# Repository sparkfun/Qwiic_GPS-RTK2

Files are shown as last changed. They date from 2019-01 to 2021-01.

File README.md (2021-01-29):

SparkFun Ublox GPS-RTK-SMA (Qwiic) - ZED-F9P
===========================================================

SparkFun GPS-RTK-SMA - ZED-F9P (https://www.sparkfun.com/products/16481)

[*SparkFun GPS-RTK-SMA - ZED-F9P (GPS-16481)*](https://www.sparkfun.com/products/16481)

The ZED-F9P module is the top-of-the-line module for high accuracy GNSS and GPS location solutions including RTK. The ZED-F9P is unique in that it can receive both L1 and L2 GPS bands as well as up to four constellations (GPS, GLONASS, BeiDou, Galileo) at the same time. This module is capable of 10mm positional accuracy and has survey-in mode allowing the module to become a base station and produce RTCM 3.x correction data. 

**Words, words, words. What does it look like?!** I'm glad you asked!

SparkFun GPS-RTK2 - ZED-F9P (https://www.sparkfun.com/products/16481)

With *33* satellites used in the location solution.

Repository Contents
-------------------

* **/Documents** - Ublox datasheets and various whitepapers around RTK
* **/Hardware** - Eagle files

Documentation
--------------

* **[Installing an Arduino Library Guide](https://learn.sparkfun.com/tutorials/installing-an-arduino-library)** - Basic information on how to install an Arduino library.
* **[Arduino Library](https://github.com/sparkfun/SparkFun_u-blox_GNSS_Arduino_Library)** - Arduino Library for Ublox modules.
* **[Hookup Guide](https://learn.sparkfun.com/tutorials/gps-rtk2-hookup-guide)** - Hookup guide for the SparkFun Ublox GPS-RTK-SMA.

License Information
-------------------

This product is _**open source**_! 

Various bits of the code have different licenses applied. Anything SparkFun wrote is beerware; if you see me (or any other SparkFun employee) at the local, and you've found our code helpful, please buy us a round!

Please use, reuse, and modify these files as you see fit. Please maintain attribution to SparkFun Electronics and release anything derivative under the same license.

Distributed as-is; no warranty is given.

- Your friends at SparkFun.

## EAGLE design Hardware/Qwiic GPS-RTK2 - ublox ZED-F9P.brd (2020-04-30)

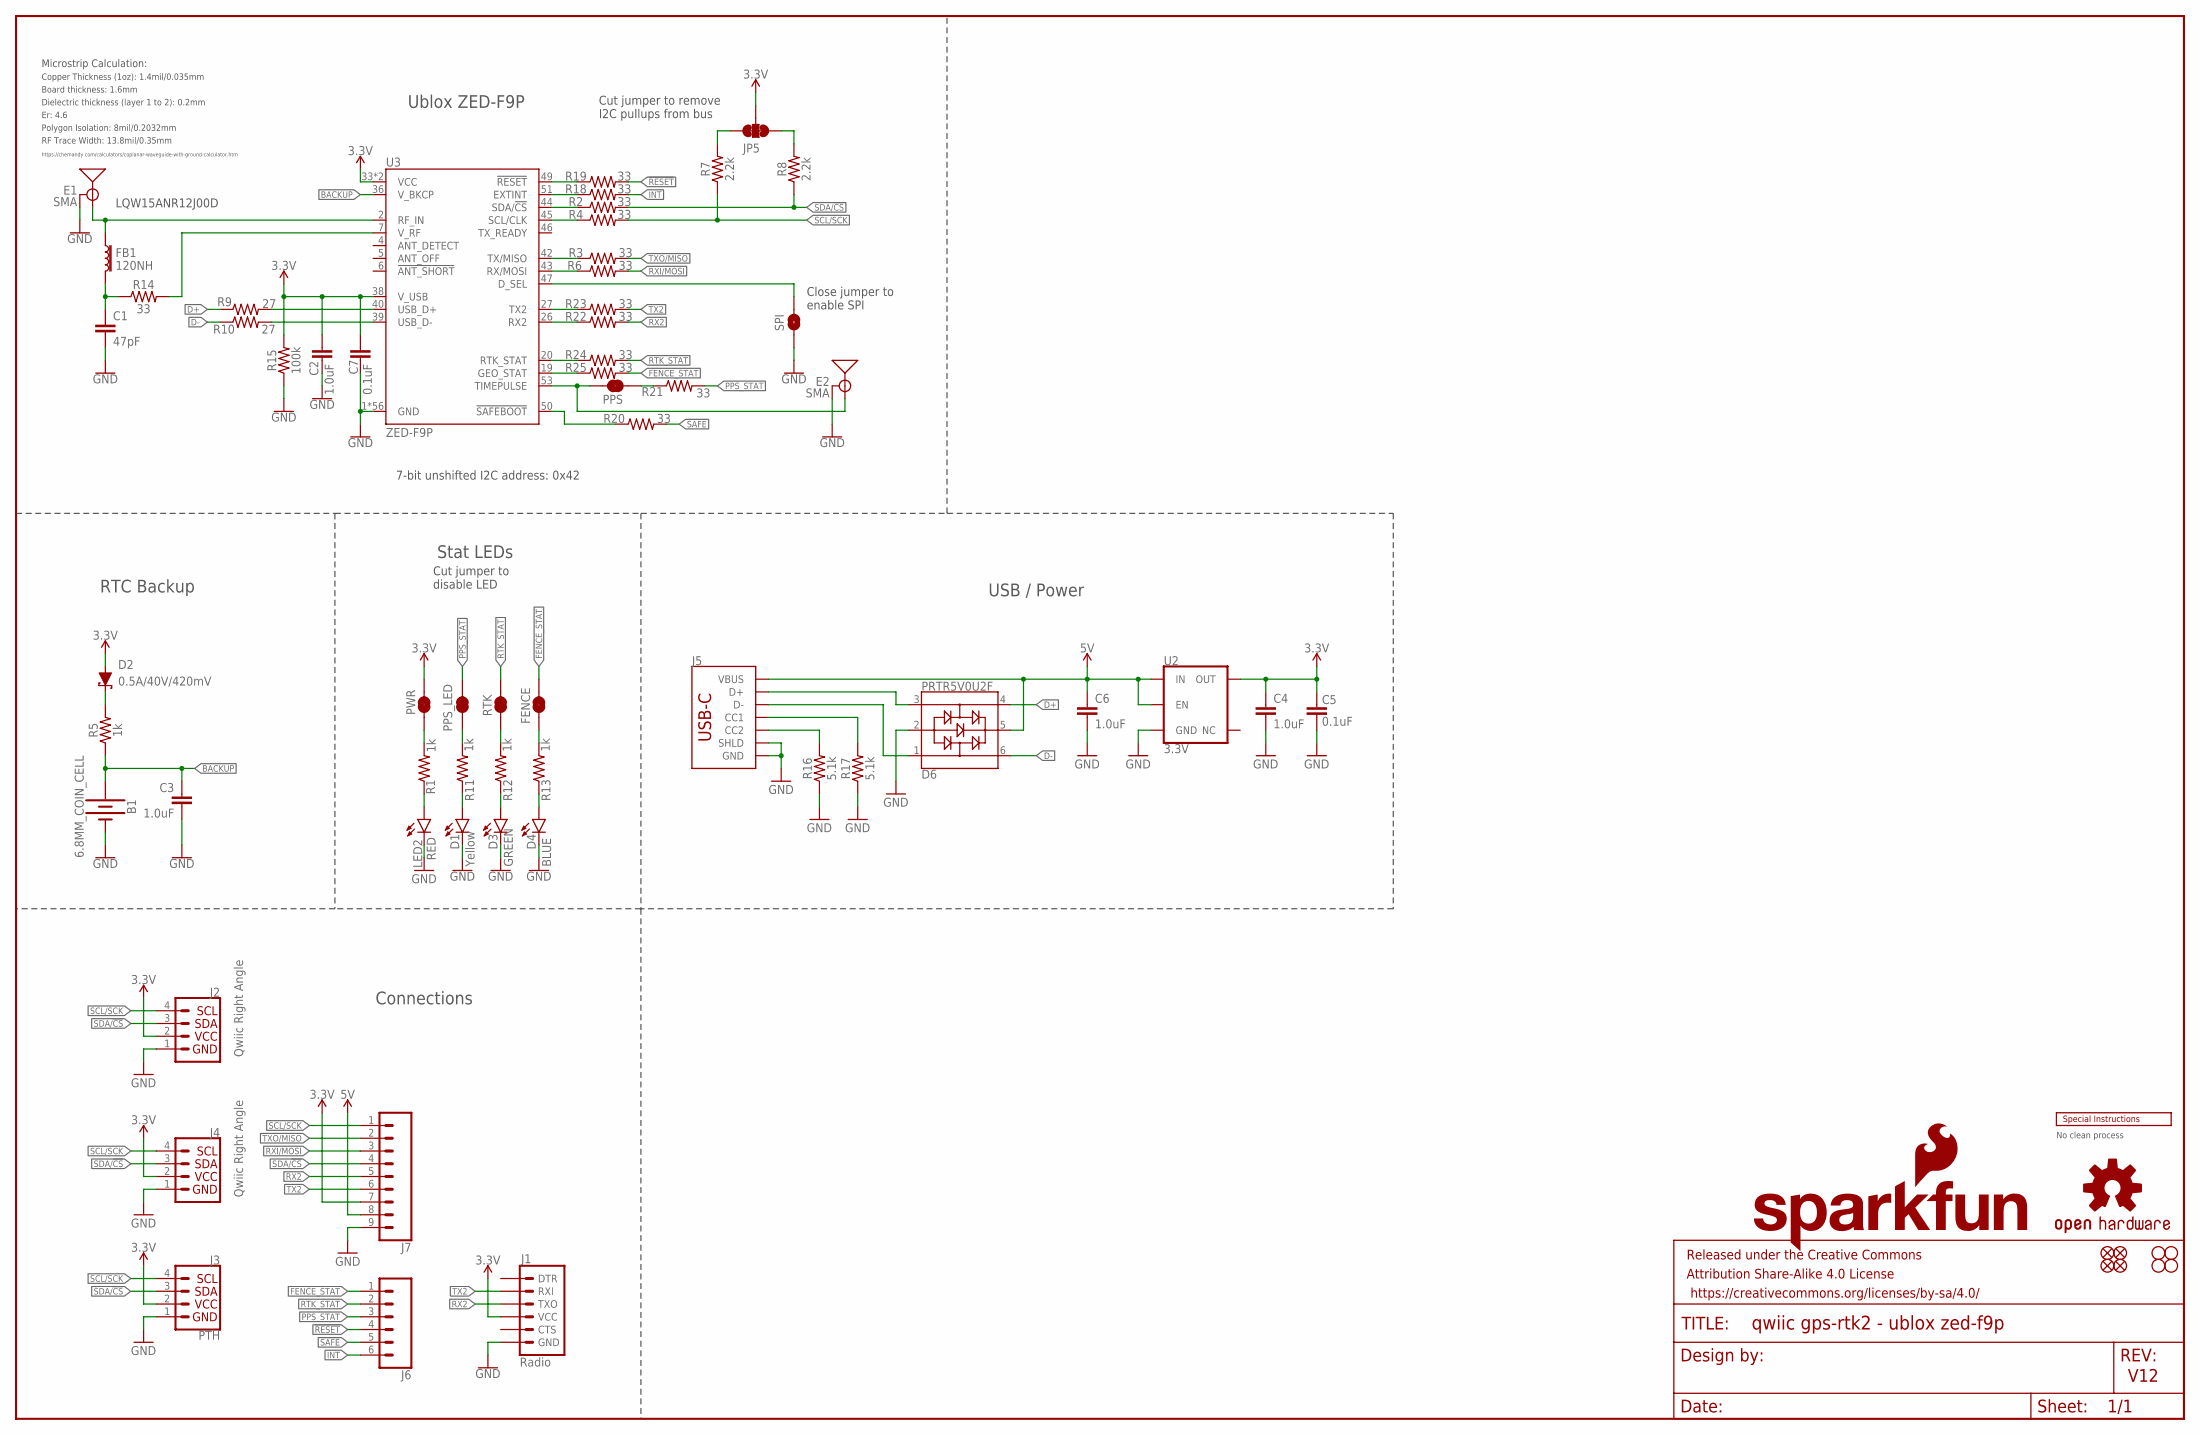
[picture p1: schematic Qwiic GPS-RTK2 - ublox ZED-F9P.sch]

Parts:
B1: 6.8MM_COIN_CELL; ML414H_IV01E
C1: 47pF; 0402
C2, C3, C4, C6: 1.0uF; 0603
C5, C7: 0.1uF; 0603
D1: Yellow; LED-0603
D2: 0.5A/40V/420mV; SOD-323
D3: GREEN; LED-0603
D4: BLUE; LED-0603
D6: PRTR5V0U2F; SOT886
E1, E2: SMA; SMA-EDGE
FB1: 120NH; 0402_MURATA
FENCE: JUMPER-SMT_2_NC_TRACE_SILK; SMT-JUMPER_2_NC_TRACE_SILK
FRAME2: FRAME-LEDGER; CREATIVE_COMMONS
J1: Radio; 1X06_NO_SILK
J2, J4: Qwiic Right Angle; JST04_1MM_RA
J3: PTH; 1X04_NO_SILK
J5: USB_C_2-LAYER_PADS; USB-C-16P-2LAYER-PADS
J6: CONN_06NO_SILK_FEMALE_PTH; 1X06_NO_SILK
J7: CONN_09NO_SILK; 1X09_NO_SILK
JP5: JUMPER-SMT_3_2-NC_TRACE_SILK; SMT-JUMPER_3_2-NC_TRACE_SILK
JP21, JP61, JP71, JP81: FIDUCIALUFIDUCIAL; MICRO-FIDUCIAL
JP31, JP41, JP91, JP101: STAND-OFF
LED2: RED; LED-0603
LOGO1: OSHW-LOGOMINI; OSHW-LOGO-MINI
LOGO2: SFE_LOGO_NAME_FLAME.1_INCH; SFE_LOGO_NAME_FLAME_.1
PPS: JUMPER-SMT_2_NC_TRACE_SILK; SMT-JUMPER_2_NC_TRACE_SILK
PPS_LED: JUMPER-SMT_2_NC_TRACE_SILK; SMT-JUMPER_2_NC_TRACE_SILK
PWR: JUMPER-SMT_2_NC_TRACE_SILK; SMT-JUMPER_2_NC_TRACE_SILK
R1, R5, R11, R12, R13: 1k; 0603
R2, R3, R4, R6, R14, R18, R19, R20, R21, R22, R23, R24, R25: 33; 0603
R7, R8: 2.2k; 0603
R9, R10: 27; 0603
R15: 100k; 0603
R16, R17: 5.1k; 0603
RTK: JUMPER-SMT_2_NC_TRACE_SILK; SMT-JUMPER_2_NC_TRACE_SILK
SPI: JUMPER-SMT_2_NO_SILK; SMT-JUMPER_2_NO_SILK
U2: 3.3V; SOT23-5
U3: ZED-F9P
U$2: SPECIAL_INSTRUCTIONS-ORDERING; ORDERING_INSTRUCTIONS

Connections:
3.3V: C2.1, C4.1, C5.2, C7.2, D2.A, J1.4 (VCC), J2.2, J3.2 (VCC), J4.2, J7.7, JP5.2, PWR.2, R15.2, U2.5 (OUT), U3.33 (VCC), U3.34 (VCC), U3.38 (V_USB)
5V: C6.1, D6.5, J5.VBUS1 (VBUS), J5.VBUS2 (VBUS), J7.8, U2.1 (IN), U2.3 (EN)
!RESET: J6.4, R19.2
!SAFE: J6.5, R20.2
ANT_VCC: C1.1, FB1.P2 (2), R14.1
BACKUP: B1.+, C3.1, R5.1, U3.36 (V_BKCP)
CC1: J5.A5 (CC1), R17.2
CC2: J5.B5 (CC2), R16.2
D+: D6.4, R9.1
D-: D6.6, R10.1
D_SEL: SPI.2, U3.47 (D_SEL)
FENCE_STAT: FENCE.2, J6.1, R25.2
GND: B1.-, C1.2, C2.2, C3.2, C4.2, C5.1, C6.2, C7.1, D1.C, D3.C, D4.C, D6.2, E1.GND@0 (GND), E1.GND@1 (GND), E1.GND@2 (GND), E1.GND@3 (GND), E2.GND@0 (GND), E2.GND@1 (GND), E2.GND@2 (GND), E2.GND@3 (GND), J1.6 (GND), J2.1, J3.1 (GND), J4.1, J5.GND, J5.GND2 (GND), J5.SHLD1 (SHLD), J5.SHLD2 (SHLD), J5.SHLD3 (SHLD), J5.SHLD4 (SHLD), J7.9, LED2.C, R15.1, R16.1, R17.1, SPI.1, U2.2 (GND), U3.1 (GND), U3.3 (GND), U3.12 (GND), U3.14 (GND), U3.32 (GND), U3.37 (GND), U3.41 (GND), U3.48 (GND), U3.55 (GND), U3.56 (GND), U3.57 (GND), U3.58 (GND), U3.59 (GND), U3.60 (GND), U3.61 (GND), U3.62 (GND), U3.63 (GND), U3.64 (GND), U3.65 (GND), U3.66 (GND), U3.67 (GND), U3.68 (GND), U3.69 (GND), U3.70 (GND), U3.71 (GND), U3.72 (GND), U3.73 (GND), U3.74 (GND), U3.75 (GND), U3.76 (GND), U3.77 (GND), U3.78 (GND), U3.79 (GND), U3.80 (GND), U3.81 (GND), U3.82 (GND), U3.83 (GND), U3.84 (GND), U3.85 (GND), U3.86 (GND), U3.87 (GND), U3.88 (GND), U3.89 (GND), U3.90 (GND), U3.91 (GND), U3.92 (GND), U3.93 (GND), U3.94 (GND), U3.95 (GND), U3.96 (GND), U3.97 (GND), U3.98 (GND), U3.99 (GND), U3.100 (GND), U3.101 (GND), U3.102 (GND)
GPS_ANT1: E1.SIG (SIGNAL), FB1.P1 (1), U3.2 (RF_IN)
INT: J6.6, R18.2
unnamed: D3.A, R12.1
unnamed: D1.A, R11.1
unnamed: R12.2, RTK.1
unnamed: PPS_LED.1, R11.2
unnamed: JP5.1, R8.2
unnamed: D2.C, R5.2
unnamed: D4.A, R13.1
unnamed: JP5.3, R7.2
unnamed: FENCE.1, R13.2
unnamed: LED2.A, R1.1
unnamed: R9.2, U3.40 (USB_D+)
unnamed: R10.2, U3.39 (USB_D-)
unnamed: R14.2, U3.7 (V_RF)
unnamed: R22.1, U3.26 (RX2)
unnamed: R18.1, U3.51 (EXTINT)
unnamed: R19.1, U3.49 (!RESET!)
unnamed: PWR.1, R1.2
unnamed: R20.1, U3.50 (!SAFEBOOT!)
unnamed: R24.1, U3.20 (RTK_STAT)
unnamed: R25.1, U3.19 (GEO_STAT)
unnamed: PPS.1, R21.1
PPS: E2.SIG (SIGNAL), PPS.2, U3.53 (TIMEPULSE)
PPS_STAT: J6.3, PPS_LED.2, R21.2
RTK_STAT: J6.2, R24.2, RTK.2
RX2: J1.3 (TXO), J7.5, R22.2
RXI/MOSI: J7.3, R6.2
RXLV: R6.1, U3.43 (RX/MOSI)
SCL/SCK: J2.4, J3.4 (SCL), J4.4, J7.1, R4.2, R7.1
SCL_LV: R4.1, U3.45 (SCL/CLK)
SDA/!CS: J2.3, J3.3 (SDA), J4.3, J7.4, R2.2, R8.1
SDA_LV: R2.1, U3.44 (SDA/!CS!)
TX2: J1.2 (RXI), J7.6, R23.2
TX2_P: R23.1, U3.27 (TX2)
TXLV: R3.1, U3.42 (TX/MISO)
TXO/MISO: J7.2, R3.2
UNP_D+: D6.3, J5.A6 (D+), J5.B6 (D+)
UNP_D-: D6.1, J5.A7 (D-), J5.B7 (D-)

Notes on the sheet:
V12
7-bit unshifted I2C address: 0x42
Ublox ZED-F9P
RTC Backup
Stat LEDs
Cut jumper to remove I2C pullups from bus
Cut jumper to disable LED
Close jumper to enable SPI
LQW15ANR12J00D
Board thickness: 1.6mm
Er: 4.6
Copper Thickness (1oz): 1.4mil/0.035mm
RF Trace Width: 13.8mil/0.35mm
Polygon Isolation: 8mil/0.2032mm
No clean process
Dielectric thickness (layer 1 to 2): 0.2mm
https://chemandy.com/calculators/coplanar-waveguide-with-ground-calculator.htm
Microstrip Calculation:
Connections
USB / Power

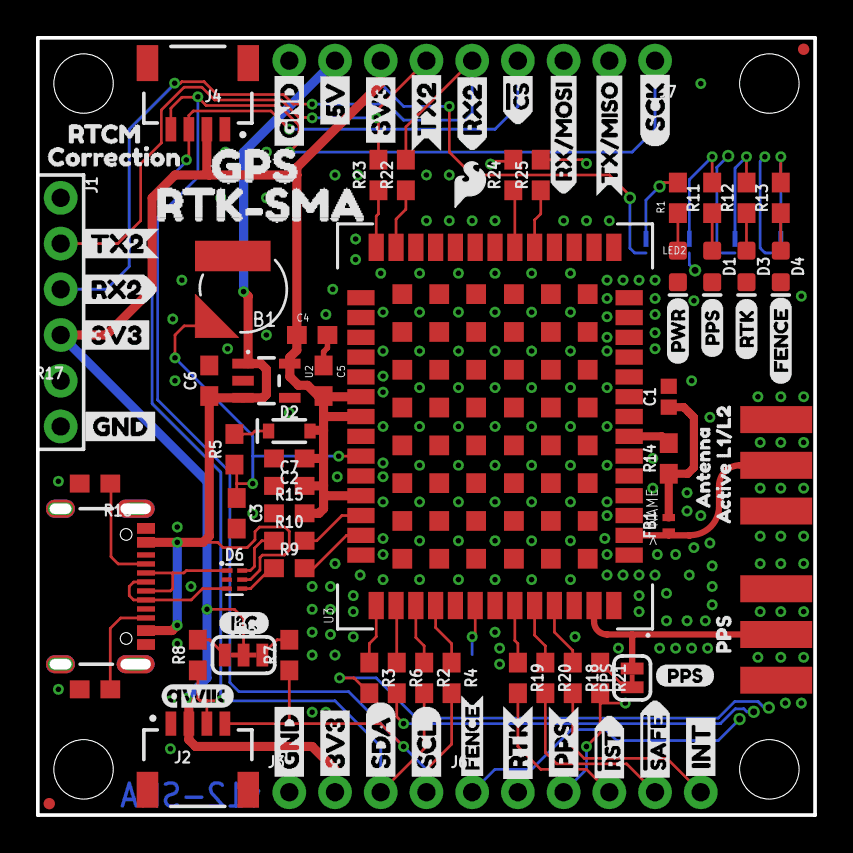
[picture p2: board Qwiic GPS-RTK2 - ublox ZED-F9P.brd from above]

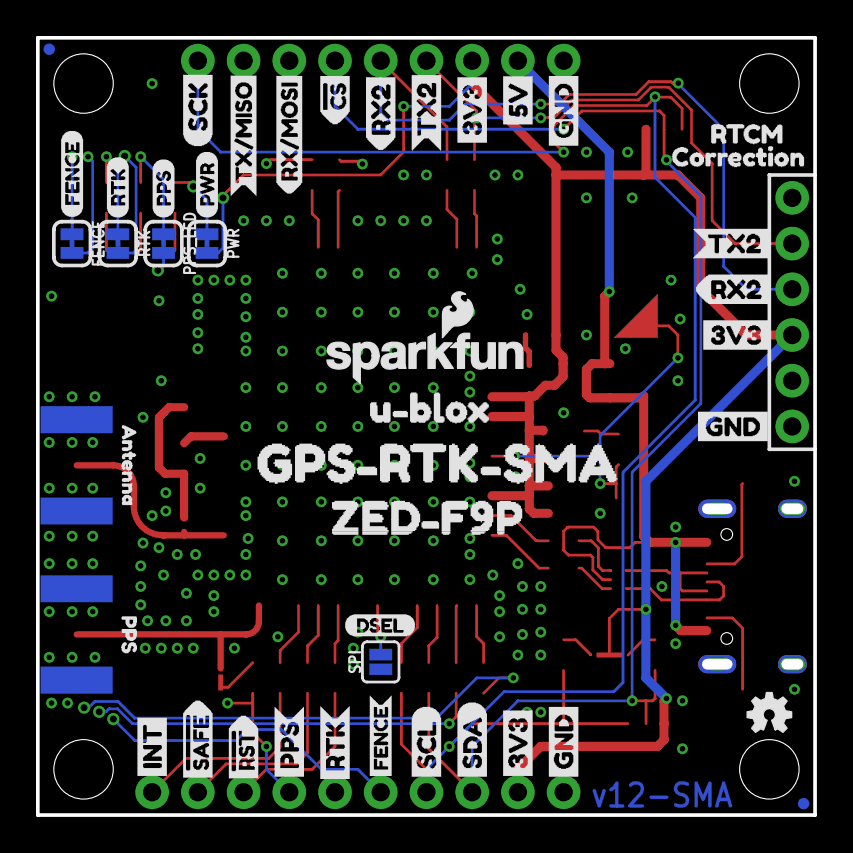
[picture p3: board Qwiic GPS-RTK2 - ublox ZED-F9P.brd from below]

Board: 4 copper layers, 43.2 x 43.2 mm, 143 parts (44 on the bottom side), 52 nets.

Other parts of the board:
U$1, U$4: SDA-[)
U$3, U$5: SCL-[)
U$6, U$7, U$60, U$61, U$66, U$67: 3V3-04
U$8, U$9, U$62, U$63: GND-04
U$10: I_SUPER2_C-()-03
U$11, U$54: FENCE2
U$12, U$18: PWR-()-03
U$13, U$28, U$29, U$32: RTK1
U$14, U$17: FENCE0
U$15, U$16: INT8
U$19, U$20: 5V
U$21, U$56, U$58: RX20
U$22: U#BLOX3
U$23, U$24: CS#-<]
U$25, U$52, U$72: PPS0
U$26, U$31: RX#MOSI3
U$27: DSEL0
U$30: QWIIC_4MM
U$33: SFE_LOGO_FLAME_.1
U$34, U$37: TX#MISO1
U$35, U$36: #RST3
U$38, U$41: SCK-(]-04
U$39, U$40: #SAFE1
U$42: RX22
U$43, U$44: PPS5
U$45, U$68: GND3
U$47, U$74: PPS1
U$48, U$70: RTCM5
U$49: ZED#F9P6
U$50, U$55, U$57: TX21
U$51: TX23
U$53, U$69: CORRECTION0
U$59: GPS0
U$65: ACTIVE_L1#L21
U$71, U$75: ANTENNA2
U$73: RTK#SMA4
U$76: GPS#RTK#SMA5

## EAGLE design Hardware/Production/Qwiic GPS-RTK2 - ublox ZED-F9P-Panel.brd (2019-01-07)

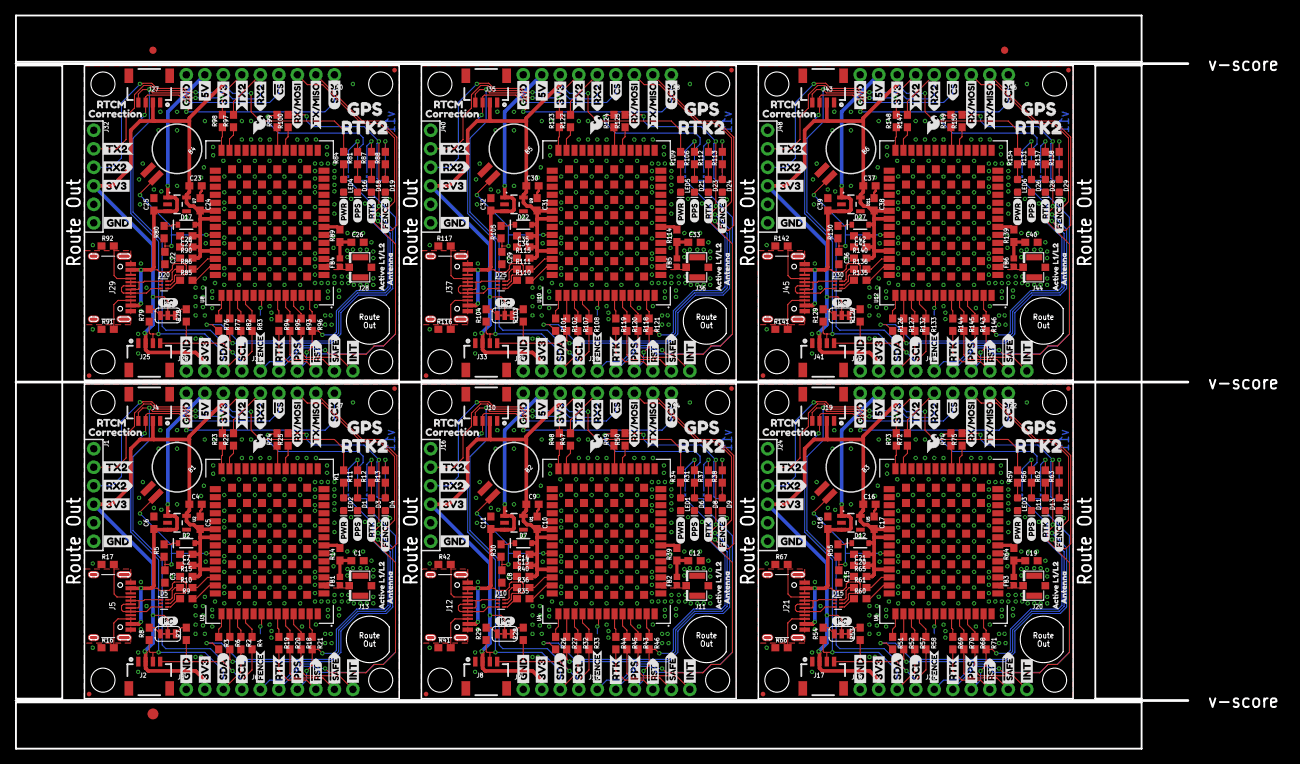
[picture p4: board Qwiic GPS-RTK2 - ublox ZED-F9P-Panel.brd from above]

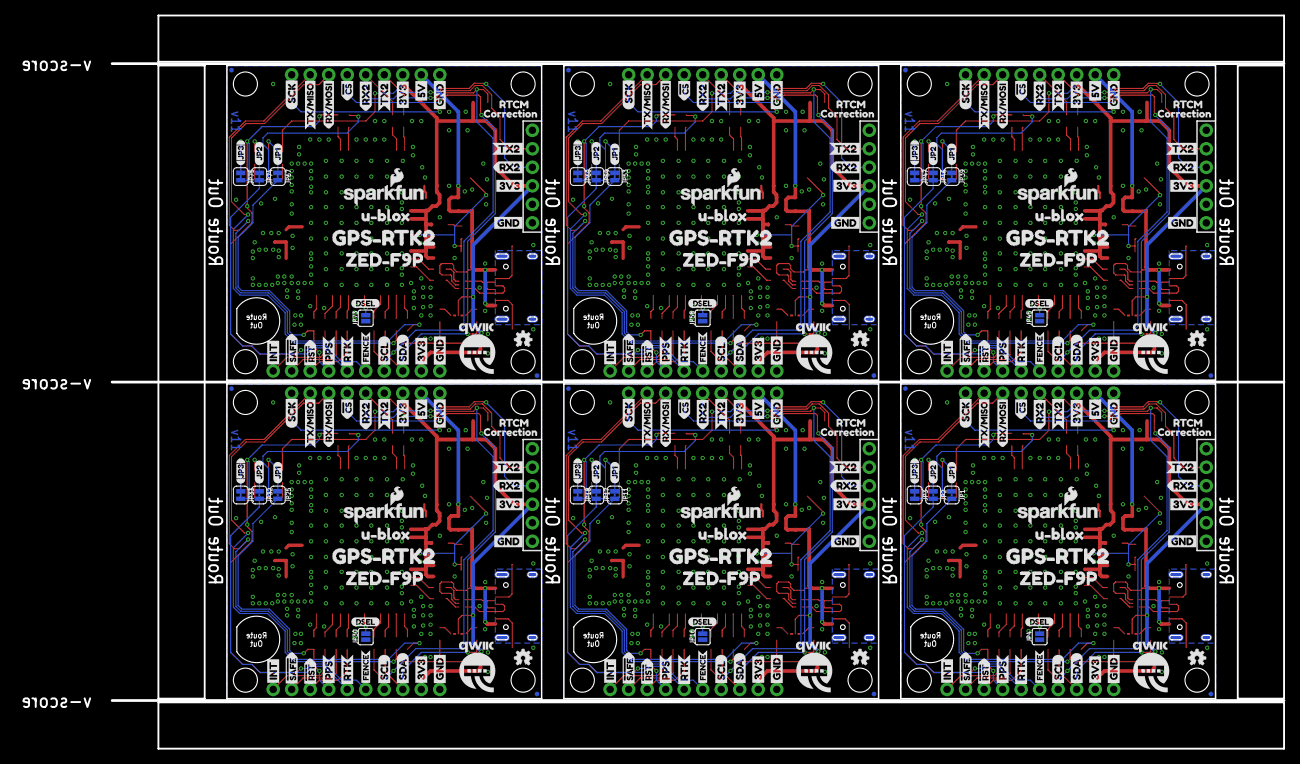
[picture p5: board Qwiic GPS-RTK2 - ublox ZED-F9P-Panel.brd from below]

Board: 2 copper layers, 160.8 x 100.6 mm, 807 parts (246 on the bottom side), 306 nets.

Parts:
B1, B2, B3, B4, B5, B6: 6.8MM_COIN_CELL; BATTCON-6.8MM
C1, C12, C19, C26, C33, C40: 47pF; 0603
C2, C3, C4, C6, C8, C9, C11, C13, C15, C16, C18, C20, C22, C23, C25, C27, C29, C30, C32, C34, C36, C37, C39, C41: 1.0uF; 0603
C5, C7, C10, C14, C17, C21, C24, C28, C31, C35, C38, C42: 0.1uF; 0603
D1, D6, D11, D16, D21, D26: Yellow; LED-0603
D2, D7, D12, D17, D22, D27: 0.5A/40V/420mV; SOD-323
D3, D8, D13, D18, D23, D28: GREEN; LED-0603
D4, D9, D14, D19, D24, D29: BLUE; LED-0603
D5, D10, D15, D20, D25, D30: PRTR5V0U2F; SOT886
E$1, E$2: FIDUCIAL-1X2
E$3: FIDUCIAL-1.5X3
FB1, FB2, FB3, FB4, FB5, FB6: FERRITE_BEAD-120_OHM-0402; 0402
J1, J16, J24, J32, J40, J48: Radio; 1X06_NO_SILK
J2, J4, J8, J10, J17, J19, J25, J27, J33, J35, J41, J43: 1X04_1MM_RA
J3, J9, J18, J26, J34, J42: PTH; 1X04_NO_SILK
J5, J12, J21, J29, J37, J45: USB-C-16P
J6, J15, J23, J31, J39, J47: 1X06_NO_SILK
J7, J14, J22, J30, J38, J46: 1X09_NO_SILK
J11, J13, J20, J28, J36, J44: U.FL
JP1, JP2, JP3, JP11, JP17, JP18, JP25, JP32, JP33, JP39, JP46, JP47, JP53, JP59, JP60, JP67, JP74, JP75: SMT-JUMPER_2_NC_TRACE_SILK
JP4, JP16, JP30, JP45, JP58, JP73: SMT-JUMPER_2_NO_SILK
JP5, JP10, JP24, JP38, JP52, JP66: SMT-JUMPER_3_2-NC_TRACE_SILK
JP6, JP7, JP14, JP15, JP19, JP20, JP28, JP29, JP31, JP34, JP35, JP41, JP43, JP44, JP48, JP49, JP56, JP57, JP62, JP63, JP70, JP72, JP91, JP101: STAND-OFF
JP8, JP9, JP12, JP13, JP21, JP22, JP23, JP26, JP27, JP36, JP37, JP40, JP42, JP50, JP51, JP54, JP55, JP61, JP64, JP65, JP68, JP69, JP71, JP81: FIDUCIALUFIDUCIAL; MICRO-FIDUCIAL
LED1, LED2, LED3, LED4, LED5, LED6: RED; LED-0603
LOGO1, LOGO3, LOGO5, LOGO7, LOGO9, LOGO11: OSHW-LOGOMINI; OSHW-LOGO-MINI
LOGO2, LOGO4, LOGO6, LOGO8, LOGO10, LOGO12: SFE_LOGO_NAME_FLAME.1_INCH; SFE_LOGO_NAME_FLAME_.1
R1, R5, R11, R12, R13, R30, R31, R34, R37, R38, R55, R56, R59, R62, R63, R80, R81, R84, R87, R88, R105, R106, R109, R112, R113, R130, R131, R134, R137, R138: 1k; 0603
R2, R3, R4, R6, R18, R19, R20, R21, R22, R23, R24, R25, R26, R27, R32, R33, R43, R44, R45, R46, R47, R48, R49, R50, R51, R52, R57, R58, R68, R69, R70, R71, R72, R73, R74, R75, R76, R77, R82, R83, R93, R94, R95, R96, R97, R98, R99, R100, R101, R102, R107, R108, R118, R119, R120, R121, R122, R123, R124, R125, R126, R127, R132, R133, R143, R144, R145, R146, R147, R148, R149, R150: 33; 0603
R7, R8, R28, R29, R53, R54, R78, R79, R103, R104, R128, R129: 2.2k; 0603
R9, R10, R35, R36, R60, R61, R85, R86, R110, R111, R135, R136: 27; 0603
R14, R39, R64, R89, R114, R139: 10; 0603
R15, R40, R65, R90, R115, R140: 100k; 0603
R16, R17, R41, R42, R66, R67, R91, R92, R116, R117, R141, R142: 5.1k; 0603
U1, U2, U5, U7, U9, U11: 3.3V; SOT23-5
U3, U4, U6, U8, U10, U12: ZED-F9P
U$1, U$2, U$4, U$72, U$139, U$141, U$208, U$210, U$277, U$279, U$346, U$348: SDA-[)
U$3, U$5, U$47, U$73, U$140, U$142, U$209, U$211, U$278, U$280, U$347, U$349: SCL-[)
U$6, U$7, U$60, U$61, U$66, U$67, U$74, U$75, U$97, U$98, U$116, U$117, U$143, U$144, U$166, U$167, U$185, U$186, U$212, U$213, U$235, U$236, U$254, U$255, U$281, U$282, U$304, U$305, U$323, U$324, U$350, U$351, U$373, U$374, U$392, U$393: 3V3-04
U$8, U$9, U$62, U$63, U$76, U$77, U$99, U$100, U$145, U$146, U$168, U$169, U$214, U$215, U$237, U$238, U$283, U$284, U$306, U$307, U$352, U$353, U$375, U$376: GND-04
U$10, U$78, U$147, U$216, U$285, U$354: I_SUPER2_C-()-03
U$11, U$90, U$159, U$228, U$297, U$366: FENCE2
U$12, U$91, U$160, U$229, U$298, U$367: JP20
U$13, U$28, U$29, U$92, U$95, U$96, U$161, U$164, U$165, U$230, U$233, U$234, U$299, U$302, U$303, U$368, U$371, U$372: RTK1
U$14, U$17, U$93, U$94, U$162, U$163, U$231, U$232, U$300, U$301, U$369, U$370: FENCE0
U$15, U$16, U$79, U$80, U$148, U$149, U$217, U$218, U$286, U$287, U$355, U$356: INT8
U$18, U$104, U$173, U$242, U$311, U$380: PWR-()-03
U$19, U$20, U$105, U$106, U$174, U$175, U$243, U$244, U$312, U$313, U$381, U$382: 5V
U$21, U$56, U$58, U$129, U$134, U$136, U$198, U$203, U$205, U$267, U$272, U$274, U$336, U$341, U$343, U$405, U$410, U$412: RX20
U$22, U$81, U$150, U$219, U$288, U$357: U#BLOX3
U$23, U$24, U$107, U$108, U$176, U$177, U$245, U$246, U$314, U$315, U$383, U$384: CS#-<]
U$25, U$101, U$170, U$239, U$308, U$377: JP10
U$26, U$31, U$112, U$124, U$181, U$193, U$250, U$262, U$319, U$331, U$388, U$400: RX#MOSI3
U$27, U$103, U$172, U$241, U$310, U$379: DSEL0
U$30, U$82, U$151, U$220, U$289, U$358: QWIIC-LOGO-MEDIUM
U$32, U$102, U$171, U$240, U$309, U$378: JP32
U$33, U$111, U$180, U$249, U$318, U$387: SFE_LOGO_FLAME_.1
U$34, U$37, U$113, U$125, U$182, U$194, U$251, U$263, U$320, U$332, U$389, U$401: TX#MISO1
U$35, U$36, U$83, U$84, U$152, U$153, U$221, U$222, U$290, U$291, U$359, U$360: #RST3
U$38, U$41, U$109, U$110, U$178, U$179, U$247, U$248, U$316, U$317, U$385, U$386: SCK-(]-04
U$39, U$40, U$85, U$86, U$154, U$155, U$223, U$224, U$292, U$293, U$361, U$362: #SAFE1
U$42, U$130, U$199, U$268, U$337, U$406: RX22
U$43, U$44, U$87, U$88, U$156, U$157, U$225, U$226, U$294, U$295, U$363, U$364: PPS5
U$45, U$68, U$114, U$118, U$183, U$187, U$252, U$256, U$321, U$325, U$390, U$394: GND3
U$46, U$115, U$184, U$253, U$322, U$391: GPS#RTK28
U$48, U$70, U$120, U$122, U$189, U$191, U$258, U$260, U$327, U$329, U$396, U$398: RTCM5
U$49, U$121, U$190, U$259, U$328, U$397: ZED#F9P6
U$50, U$55, U$57, U$131, U$133, U$135, U$200, U$202, U$204, U$269, U$271, U$273, U$338, U$340, U$342, U$407, U$409, U$411: TX21
U$51, U$132, U$201, U$270, U$339, U$408: TX23
U$52, U$89, U$158, U$227, U$296, U$365: PPS0
U$53, U$69, U$119, U$123, U$188, U$192, U$257, U$261, U$326, U$330, U$395, U$399: CORRECTION0
U$54, U$126, U$195, U$264, U$333, U$402: SMA-ANTENNA-THREADED; SMA-THREADED
U$59, U$137, U$206, U$275, U$344, U$413: GPS0
U$64, U$138, U$207, U$276, U$345, U$414: RTK21
U$65, U$127, U$196, U$265, U$334, U$403: ACTIVE_L1#L21
U$71, U$128, U$197, U$266, U$335, U$404: ANTENNA2

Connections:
3.3V: C2.1, C4.1, C5.2, C7.2, D2.A, J1.4, J2.2, J3.2, J4.2, J7.7, JP5.2, R1.2, R15.2, U2.5, U3.33, U3.34, U3.38
3.3V1: C9.1, C10.2, C13.1, C14.2, D7.A, J8.2, J9.2, J10.2, J14.7, J16.4, JP10.2, R34.2, R40.2, U1.5, U4.33, U4.34, U4.38
3.3V2: C16.1, C17.2, C20.1, C21.2, D12.A, J17.2, J18.2, J19.2, J22.7, J24.4, JP24.2, R59.2, R65.2, U5.5, U6.33, U6.34, U6.38
3.3V3: C23.1, C24.2, C27.1, C28.2, D17.A, J25.2, J26.2, J27.2, J30.7, J32.4, JP38.2, R84.2, R90.2, U7.5, U8.33, U8.34, U8.38
3.3V4: C30.1, C31.2, C34.1, C35.2, D22.A, J33.2, J34.2, J35.2, J38.7, J40.4, JP52.2, R109.2, R115.2, U9.5, U10.33, U10.34, U10.38
3.3V5: C37.1, C38.2, C41.1, C42.2, D27.A, J41.2, J42.2, J43.2, J46.7, J48.4, JP66.2, R134.2, R140.2, U11.5, U12.33, U12.34, U12.38
5V: C6.1, D5.5, J5.VBUS1, J5.VBUS2, J7.8, U2.1, U2.3
5V1: C11.1, D10.5, J12.VBUS1, J12.VBUS2, J14.8, U1.1, U1.3
5V2: C18.1, D15.5, J21.VBUS1, J21.VBUS2, J22.8, U5.1, U5.3
5V3: C25.1, D20.5, J29.VBUS1, J29.VBUS2, J30.8, U7.1, U7.3
5V4: C32.1, D25.5, J37.VBUS1, J37.VBUS2, J38.8, U9.1, U9.3
5V5: C39.1, D30.5, J45.VBUS1, J45.VBUS2, J46.8, U11.1, U11.3
!RESET: J6.4, R19.2
!RESET1: J15.4, R44.2
!RESET2: J23.4, R69.2
!RESET3: J31.4, R94.2
!RESET4: J39.4, R119.2
!RESET5: J47.4, R144.2
!SAFE: J6.5, R20.2
!SAFE1: J15.5, R45.2
!SAFE2: J23.5, R70.2
!SAFE3: J31.5, R95.2
!SAFE4: J39.5, R120.2
!SAFE5: J47.5, R145.2
ANT_VCC: C1.1, FB1.2, R14.1
ANT_VCC1: C12.1, FB2.2, R39.1
ANT_VCC2: C19.1, FB3.2, R64.1
ANT_VCC3: C26.1, FB4.2, R89.1
ANT_VCC4: C33.1, FB5.2, R114.1
ANT_VCC5: C40.1, FB6.2, R139.1
BACKUP: B1.+, C3.1, R5.1, U3.36
BACKUP1: B2.+, C8.1, R30.1, U4.36
BACKUP2: B3.+, C15.1, R55.1, U6.36
BACKUP3: B4.+, C22.1, R80.1, U8.36
BACKUP4: B5.+, C29.1, R105.1, U10.36
BACKUP5: B6.+, C36.1, R130.1, U12.36
CC1: J5.A5, R17.2
CC2: J5.B5, R16.2
CC3: J12.A5, R42.2
CC4: J12.B5, R41.2
CC5: J21.A5, R67.2
CC6: J21.B5, R66.2
CC7: J29.A5, R92.2
CC8: J29.B5, R91.2
CC9: J37.A5, R117.2
CC10: J37.B5, R116.2
CC11: J45.A5, R142.2
CC12: J45.B5, R141.2
D+: D5.4, R9.1
D+1: D10.4, R35.1
D+2: D15.4, R60.1
D+3: D20.4, R85.1
D+4: D25.4, R110.1
D+5: D30.4, R135.1
D-: D5.6, R10.1
D-1: D10.6, R36.1
D-2: D15.6, R61.1
D-3: D20.6, R86.1
D-4: D25.6, R111.1
D-5: D30.6, R136.1
D_SEL: JP4.2, U3.47
D_SEL1: JP16.2, U4.47
D_SEL2: JP30.2, U6.47
D_SEL3: JP45.2, U8.47
D_SEL4: JP58.2, U10.47
D_SEL5: JP73.2, U12.47
FENCE_STAT: J6.1, JP3.2, R25.2
FENCE_STAT1: J15.1, JP18.2, R50.2
FENCE_STAT2: J23.1, JP33.2, R75.2
FENCE_STAT3: J31.1, JP47.2, R100.2
FENCE_STAT4: J39.1, JP60.2, R125.2
FENCE_STAT5: J47.1, JP75.2, R150.2
GND: B1.-, C1.2, C2.2, C3.2, C4.2, C5.1, C6.2, C7.1, D1.C, D3.C, D4.C, D5.2, J1.6, J2.1, J3.1, J4.1, J5.GND, J5.GND2, J7.9, J13.1, J13.2, JP4.1, LED2.C, R15.1, R16.1, R17.1, U2.2, U3.1, U3.3, U3.12, U3.14, U3.32, U3.37, U3.41, U3.48, U3.55, U3.56, U3.57, U3.58, U3.59, U3.60, U3.61, U3.62, U3.63, U3.64, U3.65, U3.66, U3.67, U3.68, U3.69, U3.70, U3.71, U3.72, U3.73, U3.74, U3.75, U3.76, U3.77, U3.78, U3.79, U3.80, U3.81, U3.82, U3.83, U3.84, U3.85, U3.86, U3.87, U3.88, U3.89, U3.90, U3.91, U3.92, U3.93, U3.94, U3.95, U3.96, U3.97, U3.98, U3.99, U3.100, U3.101, U3.102
GND1: B2.-, C8.2, C9.2, C10.1, C11.2, C12.2, C13.2, C14.1, D6.C, D8.C, D9.C, D10.2, J8.1, J9.1, J10.1, J11.1, J11.2, J12.GND, J12.GND2, J14.9, J16.6, JP16.1, LED1.C, R40.1, R41.1, R42.1, U1.2, U4.1, U4.3, U4.12, U4.14, U4.32, U4.37, U4.41, U4.48, U4.55, U4.56, U4.57, U4.58, U4.59, U4.60, U4.61, U4.62, U4.63, U4.64, U4.65, U4.66, U4.67, U4.68, U4.69, U4.70, U4.71, U4.72, U4.73, U4.74, U4.75, U4.76, U4.77, U4.78, U4.79, U4.80, U4.81, U4.82, U4.83, U4.84, U4.85, U4.86, U4.87, U4.88, U4.89, U4.90, U4.91, U4.92, U4.93, U4.94, U4.95, U4.96, U4.97, U4.98, U4.99, U4.100, U4.101, U4.102
GND2: B3.-, C15.2, C16.2, C17.1, C18.2, C19.2, C20.2, C21.1, D11.C, D13.C, D14.C, D15.2, J17.1, J18.1, J19.1, J20.1, J20.2, J21.GND, J21.GND2, J22.9, J24.6, JP30.1, LED3.C, R65.1, R66.1, R67.1, U5.2, U6.1, U6.3, U6.12, U6.14, U6.32, U6.37, U6.41, U6.48, U6.55, U6.56, U6.57, U6.58, U6.59, U6.60, U6.61, U6.62, U6.63, U6.64, U6.65, U6.66, U6.67, U6.68, U6.69, U6.70, U6.71, U6.72, U6.73, U6.74, U6.75, U6.76, U6.77, U6.78, U6.79, U6.80, U6.81, U6.82, U6.83, U6.84, U6.85, U6.86, U6.87, U6.88, U6.89, U6.90, U6.91, U6.92, U6.93, U6.94, U6.95, U6.96, U6.97, U6.98, U6.99, U6.100, U6.101, U6.102
GND3: B4.-, C22.2, C23.2, C24.1, C25.2, C26.2, C27.2, C28.1, D16.C, D18.C, D19.C, D20.2, J25.1, J26.1, J27.1, J28.1, J28.2, J29.GND, J29.GND2, J30.9, J32.6, JP45.1, LED4.C, R90.1, R91.1, R92.1, U7.2, U8.1, U8.3, U8.12, U8.14, U8.32, U8.37, U8.41, U8.48, U8.55, U8.56, U8.57, U8.58, U8.59, U8.60, U8.61, U8.62, U8.63, U8.64, U8.65, U8.66, U8.67, U8.68, U8.69, U8.70, U8.71, U8.72, U8.73, U8.74, U8.75, U8.76, U8.77, U8.78, U8.79, U8.80, U8.81, U8.82, U8.83, U8.84, U8.85, U8.86, U8.87, U8.88, U8.89, U8.90, U8.91, U8.92, U8.93, U8.94, U8.95, U8.96, U8.97, U8.98, U8.99, U8.100, U8.101, U8.102
GND4: B5.-, C29.2, C30.2, C31.1, C32.2, C33.2, C34.2, C35.1, D21.C, D23.C, D24.C, D25.2, J33.1, J34.1, J35.1, J36.1, J36.2, J37.GND, J37.GND2, J38.9, J40.6, JP58.1, LED5.C, R115.1, R116.1, R117.1, U9.2, U10.1, U10.3, U10.12, U10.14, U10.32, U10.37, U10.41, U10.48, U10.55, U10.56, U10.57, U10.58, U10.59, U10.60, U10.61, U10.62, U10.63, U10.64, U10.65, U10.66, U10.67, U10.68, U10.69, U10.70, U10.71, U10.72, U10.73, U10.74, U10.75, U10.76, U10.77, U10.78, U10.79, U10.80, U10.81, U10.82, U10.83, U10.84, U10.85, U10.86, U10.87, U10.88, U10.89, U10.90, U10.91, U10.92, U10.93, U10.94, U10.95, U10.96, U10.97, U10.98, U10.99, U10.100, U10.101, U10.102
GND5: B6.-, C36.2, C37.2, C38.1, C39.2, C40.2, C41.2, C42.1, D26.C, D28.C, D29.C, D30.2, J41.1, J42.1, J43.1, J44.1, J44.2, J45.GND, J45.GND2, J46.9, J48.6, JP73.1, LED6.C, R140.1, R141.1, R142.1, U11.2, U12.1, U12.3, U12.12, U12.14, U12.32, U12.37, U12.41, U12.48, U12.55, U12.56, U12.57, U12.58, U12.59, U12.60, U12.61, U12.62, U12.63, U12.64, U12.65, U12.66, U12.67, U12.68, U12.69, U12.70, U12.71, U12.72, U12.73, U12.74, U12.75, U12.76, U12.77, U12.78, U12.79, U12.80, U12.81, U12.82, U12.83, U12.84, U12.85, U12.86, U12.87, U12.88, U12.89, U12.90, U12.91, U12.92, U12.93, U12.94, U12.95, U12.96, U12.97, U12.98, U12.99, U12.100, U12.101, U12.102
GPS_ANT1: FB1.1, J13.FEED, U3.2
GPS_ANT2: FB2.1, J11.FEED, U4.2
GPS_ANT3: FB3.1, J20.FEED, U6.2
GPS_ANT4: FB4.1, J28.FEED, U8.2
GPS_ANT5: FB5.1, J36.FEED, U10.2
GPS_ANT6: FB6.1, J44.FEED, U12.2
INT: J6.6, R18.2
INT1: J15.6, R43.2
INT2: J23.6, R68.2
INT3: J31.6, R93.2
INT4: J39.6, R118.2
INT5: J47.6, R143.2
unnamed: D3.A, R12.1
unnamed: D1.A, R11.1
unnamed: JP2.1, R12.2
unnamed: JP1.1, R11.2
unnamed: JP5.1, R8.2
unnamed: D2.C, R5.2
unnamed: D4.A, R13.1
unnamed: JP5.3, R7.2
unnamed: JP3.1, R13.2
unnamed: LED2.A, R1.1
unnamed: R9.2, U3.40
unnamed: R10.2, U3.39
unnamed: R14.2, U3.7
unnamed: R22.1, U3.26
unnamed: R18.1, U3.51
unnamed: R19.1, U3.49
unnamed: R21.1, U3.53
unnamed: R20.1, U3.50
unnamed: R24.1, U3.20
unnamed: R25.1, U3.19
unnamed: JP10.1, R29.2
unnamed: JP10.3, R28.2
unnamed: D6.A, R31.1
unnamed: JP11.1, R31.2
unnamed: D7.C, R30.2
unnamed: LED1.A, R34.1
unnamed: R35.2, U4.40
unnamed: R36.2, U4.39
unnamed: D8.A, R37.1
unnamed: JP17.1, R37.2
unnamed: D9.A, R38.1
unnamed: JP18.1, R38.2
unnamed: R39.2, U4.7
unnamed: R47.1, U4.26
unnamed: R43.1, U4.51
unnamed: R44.1, U4.49
unnamed: R46.1, U4.53
unnamed: R45.1, U4.50
unnamed: R49.1, U4.20
unnamed: R50.1, U4.19
unnamed: JP24.1, R54.2
unnamed: JP24.3, R53.2
unnamed: D11.A, R56.1
unnamed: JP25.1, R56.2
unnamed: D12.C, R55.2
unnamed: LED3.A, R59.1
unnamed: R60.2, U6.40
unnamed: R61.2, U6.39
unnamed: D13.A, R62.1
unnamed: JP32.1, R62.2
unnamed: D14.A, R63.1
unnamed: JP33.1, R63.2
unnamed: R64.2, U6.7
unnamed: R72.1, U6.26
unnamed: R68.1, U6.51
unnamed: R69.1, U6.49
unnamed: R71.1, U6.53
unnamed: R70.1, U6.50
unnamed: R74.1, U6.20
unnamed: R75.1, U6.19
unnamed: JP38.1, R79.2
unnamed: JP38.3, R78.2
unnamed: D16.A, R81.1
unnamed: JP39.1, R81.2
unnamed: D17.C, R80.2
unnamed: LED4.A, R84.1
unnamed: R85.2, U8.40
unnamed: R86.2, U8.39
unnamed: D18.A, R87.1
unnamed: JP46.1, R87.2
unnamed: D19.A, R88.1
unnamed: JP47.1, R88.2
unnamed: R89.2, U8.7
unnamed: R97.1, U8.26
unnamed: R93.1, U8.51
unnamed: R94.1, U8.49
unnamed: R96.1, U8.53
unnamed: R95.1, U8.50
unnamed: R99.1, U8.20
unnamed: R100.1, U8.19
unnamed: JP52.1, R104.2
unnamed: JP52.3, R103.2
unnamed: D21.A, R106.1
unnamed: JP53.1, R106.2
unnamed: D22.C, R105.2
unnamed: LED5.A, R109.1
unnamed: R110.2, U10.40
unnamed: R111.2, U10.39
unnamed: D23.A, R112.1
unnamed: JP59.1, R112.2
unnamed: D24.A, R113.1
unnamed: JP60.1, R113.2
unnamed: R114.2, U10.7
unnamed: R122.1, U10.26
unnamed: R118.1, U10.51
unnamed: R119.1, U10.49
unnamed: R121.1, U10.53
unnamed: R120.1, U10.50
unnamed: R124.1, U10.20
unnamed: R125.1, U10.19
unnamed: JP66.1, R129.2
unnamed: JP66.3, R128.2
unnamed: D26.A, R131.1
unnamed: JP67.1, R131.2
unnamed: D27.C, R130.2
unnamed: LED6.A, R134.1
unnamed: R135.2, U12.40
unnamed: R136.2, U12.39
unnamed: D28.A, R137.1
unnamed: JP74.1, R137.2
unnamed: D29.A, R138.1
unnamed: JP75.1, R138.2
unnamed: R139.2, U12.7
unnamed: R147.1, U12.26
unnamed: R143.1, U12.51
unnamed: R144.1, U12.49
unnamed: R146.1, U12.53
unnamed: R145.1, U12.50
unnamed: R149.1, U12.20
unnamed: R150.1, U12.19
PPS: J6.3, JP1.2, R21.2
PPS1: J15.3, JP11.2, R46.2
PPS2: J23.3, JP25.2, R71.2
PPS3: J31.3, JP39.2, R96.2
PPS4: J39.3, JP53.2, R121.2
PPS5: J47.3, JP67.2, R146.2
RTK_STAT: J6.2, JP2.2, R24.2
RTK_STAT1: J15.2, JP17.2, R49.2
RTK_STAT2: J23.2, JP32.2, R74.2
RTK_STAT3: J31.2, JP46.2, R99.2
RTK_STAT4: J39.2, JP59.2, R124.2
RTK_STAT5: J47.2, JP74.2, R149.2
RX1: J14.5, J16.3, R47.2
RX2: J1.3, J7.5, R22.2
RX3: J22.5, J24.3, R72.2
RX4: J30.5, J32.3, R97.2
RX5: J38.5, J40.3, R122.2
RX6: J46.5, J48.3, R147.2
RXI/MOSI: J7.3, R6.2
RXI/MOSI1: J14.3, R27.2
RXI/MOSI2: J22.3, R52.2
RXI/MOSI3: J30.3, R77.2
RXI/MOSI4: J38.3, R102.2
RXI/MOSI5: J46.3, R127.2
RXLV: R6.1, U3.43
RXLV1: R27.1, U4.43
RXLV2: R52.1, U6.43
RXLV3: R77.1, U8.43
RXLV4: R102.1, U10.43
RXLV5: R127.1, U12.43
SCL/SCK: J2.4, J3.4, J4.4, J7.1, R4.2, R7.1
SCL/SCK1: J8.4, J9.4, J10.4, J14.1, R28.1, R33.2
SCL/SCK2: J17.4, J18.4, J19.4, J22.1, R53.1, R58.2
SCL/SCK3: J25.4, J26.4, J27.4, J30.1, R78.1, R83.2
SCL/SCK4: J33.4, J34.4, J35.4, J38.1, R103.1, R108.2
SCL/SCK5: J41.4, J42.4, J43.4, J46.1, R128.1, R133.2
SCL_LV: R4.1, U3.45
SCL_LV1: R33.1, U4.45
SCL_LV2: R58.1, U6.45
SCL_LV3: R83.1, U8.45
SCL_LV4: R108.1, U10.45
SCL_LV5: R133.1, U12.45
SDA/!CS: J2.3, J3.3, J4.3, J7.4, R2.2, R8.1
SDA/!CS1: J8.3, J9.3, J10.3, J14.4, R29.1, R32.2
SDA/!CS2: J17.3, J18.3, J19.3, J22.4, R54.1, R57.2
SDA/!CS3: J25.3, J26.3, J27.3, J30.4, R79.1, R82.2
SDA/!CS4: J33.3, J34.3, J35.3, J38.4, R104.1, R107.2
SDA/!CS5: J41.3, J42.3, J43.3, J46.4, R129.1, R132.2
SDA_LV: R2.1, U3.44
SDA_LV1: R32.1, U4.44
SDA_LV2: R57.1, U6.44
SDA_LV3: R82.1, U8.44
SDA_LV4: R107.1, U10.44
SDA_LV5: R132.1, U12.44
SHLD: J5.SHLD1, J5.SHLD2, J5.SHLD3, J5.SHLD4, J5.SHLD5, J5.SHLD6, J5.SHLD7, J5.SHLD8
SHLD1: J12.SHLD1, J12.SHLD2, J12.SHLD3, J12.SHLD4, J12.SHLD5, J12.SHLD6, J12.SHLD7, J12.SHLD8
SHLD2: J21.SHLD1, J21.SHLD2, J21.SHLD3, J21.SHLD4, J21.SHLD5, J21.SHLD6, J21.SHLD7, J21.SHLD8
SHLD3: J29.SHLD1, J29.SHLD2, J29.SHLD3, J29.SHLD4, J29.SHLD5, J29.SHLD6, J29.SHLD7, J29.SHLD8
SHLD4: J37.SHLD1, J37.SHLD2, J37.SHLD3, J37.SHLD4, J37.SHLD5, J37.SHLD6, J37.SHLD7, J37.SHLD8
SHLD5: J45.SHLD1, J45.SHLD2, J45.SHLD3, J45.SHLD4, J45.SHLD5, J45.SHLD6, J45.SHLD7, J45.SHLD8
TX1: J14.6, J16.2, R48.2
TX2: J1.2, J7.6, R23.2
TX2_P: R23.1, U3.27
TX2_P1: R48.1, U4.27
TX2_P2: R73.1, U6.27
TX2_P3: R98.1, U8.27
TX2_P4: R123.1, U10.27
TX2_P5: R148.1, U12.27
TX3: J22.6, J24.2, R73.2
TX4: J30.6, J32.2, R98.2
TX5: J38.6, J40.2, R123.2
TX6: J46.6, J48.2, R148.2
TXLV: R3.1, U3.42
TXLV1: R26.1, U4.42
TXLV2: R51.1, U6.42
TXLV3: R76.1, U8.42
TXLV4: R101.1, U10.42
TXLV5: R126.1, U12.42
TXO/MISO: J7.2, R3.2
TXO/MISO1: J14.2, R26.2
TXO/MISO2: J22.2, R51.2
TXO/MISO3: J30.2, R76.2
TXO/MISO4: J38.2, R101.2
TXO/MISO5: J46.2, R126.2
UNP_D+: D5.3, J5.A6, J5.B6
UNP_D+1: D10.3, J12.A6, J12.B6
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

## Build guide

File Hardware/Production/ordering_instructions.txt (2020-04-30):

panel size, 109x138mm
PCB thickness, 1.6mm
number of layers, 4
soldermask color, Red
silkscreen color, White
oz copper, 1oz
finish, HASL lead free
stencils, top+bottom
pcs per panel, 6
min trace width, 0.1524mm / 0.0060in
min drill size, 0.3048mm / 0.0120in
filename to layer stackup 1/2/3/4: GTL, GL2, GL3, GBL

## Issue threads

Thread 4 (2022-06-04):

GPS accuracy worsen with another USB device

trayveet, 2022-06-04:
I have SparkFun GPS-RTK-SMA Breakout - ZED-F9P (Qwiic), I am connecting it to a ubuntu 18 machine. It runs as expected without problems until I connect another USB device, and the Horizontal and Vertical accuracies (hAcc, VAcc) become worst, and as soon as I uplug the other device from the USB, the hAcc and Vacc get back to previous ranges. The device I plug in is a realsense camera, but I also tried other USB devices and the same thing happens.
I am tryingt to run a SLAM using the GPS and the realsense camera so this issue is very important to me.
The same thing happens over windows 10 (runnig u-center), but the hAcc and Vacc get worst only for a short period of time and it gets back to normal.
I tried in a raspberry pi, Jetson Tx2 and the same happens. I also tried an USB isolator, but same issue.

Any advice of what I should do?

Thanks

trayveet, 2022-06-10:
Someone responsded in the Sparkfun forum. The issue appears to be related to USB cables creating RF interferences.

Closed 2022-06-10.

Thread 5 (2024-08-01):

RTK fix loss when reading GPS coordinate

titanX108, 2024-08-01:
Hey, I'm looking for some help with my project using a F9P RTK module with a M5Stack. I have used the NtripClient for Arduino and successfully injected the RTCM messages to the F9P.

But as soon as I read any value from the F9P model using a .get*** call the RTK fix is lost.

I can't figure out why this is or how to overcome the issue. If someone has insight on what's happening I would really appreciate.

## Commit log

2019-01-07 v11 hardware: Added add' decoupling to USB VBUS, recomended induc to ant, more 33 ohm resistors.
    [Qwiic GPS-RTK2 - ublox ZED-F9P-Panel.GBL, Qwiic GPS-RTK2 - ublox ZED-F9P-Panel.GBO, Qwiic GPS-RTK2 - ublox ZED-F9P-Panel.GBS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]
2019-01-14 Adding readme, license, and gitignore.
    [Qwiic GPS-RTK2 - ublox ZED-F9P.brd, Qwiic GPS-RTK2 - ublox ZED-F9P.sch]
2019-01-28 Adding dimensions
    [Qwiic GPS-RTK2 - ublox ZED-F9P.brd]
2020-03-25 Adding SMA connector to Antenna and SMA
    [Qwiic GPS-RTK2 - ublox ZED-F9P-Panel.GBL, Qwiic GPS-RTK2 - ublox ZED-F9P-Panel.GBO, Qwiic GPS-RTK2 - ublox ZED-F9P-Panel.GBP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]
2020-03-29 Rename panel files
    [Qwiic GPS-RTK2 - ublox ZED-F9P-Panel.brd, Qwiic GPS-RTK2 - ublox ZED-F9P.brd]
2020-04-01 Update caps to X7R. Change bead on RF input.
    [Qwiic GPS-RTK2 - ublox ZED-F9P.brd, Qwiic GPS-RTK2 - ublox ZED-F9P.sch]

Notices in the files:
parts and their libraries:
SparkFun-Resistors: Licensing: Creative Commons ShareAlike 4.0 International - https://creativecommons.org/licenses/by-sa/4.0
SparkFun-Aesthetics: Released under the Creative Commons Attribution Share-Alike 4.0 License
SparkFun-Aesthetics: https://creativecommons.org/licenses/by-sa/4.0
